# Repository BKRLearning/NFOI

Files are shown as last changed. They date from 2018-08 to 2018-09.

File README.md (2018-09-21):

****
# Kitchen Mania
****
Kitchen Mania uses screen-based game control as a starting point for understanding and exploring new methods of interacting with physical computer interfaces. It uses familiar household appliances and tools to produce novel forms of human-computer interaction that are intuitive and accessible.

One the primary goals of Kitchen Mania is to achieve functional human interface devices that simultaneously perform real physical tasks. While playful, we believe these controllers show the viability of highly accurate / low latency passive sensing of existing electronic appliances. This work has applications in a range of smart home and IoT use cases.

Setup
=========
Lorem ipsum dolor sit amet, consectetur adipiscing elit, sed do eiusmod tempor incididunt ut labore et dolore magna aliqua. Ut enim ad minim veniam, quis nostrud exercitation ullamco laboris nisi ut aliquip ex ea commodo consequat. Duis aute irure dolor in reprehenderit in voluptate velit esse cillum dolore eu fugiat nulla pariatur. Excepteur sint occaecat cupidatat non proident, sunt in culpa qui officia deserunt mollit anim id est laborum.

PulpPad
=========
The PulpPad is a controller comprised of four electric juicers with interchangeable button mapping. For this demo, we have setup two PulpPads mapped in a D-pad configuration to StepMania, a Dance Dance Revolution simulator. Hand-dance battle your friends and drink some freshly squeezed juice after you play!

conROLLER
=========
The conROLLER is a rolling pin controller designed to work with single-axis games. Roll the pin to move your player on screen // use the thumb button to fire and activate the two attached relays. Fire up your pizza oven and make some own pizza after destroying enemy ships!

Project resources
=================
- [Website](http://www.brooklynresearch.org)
- [Source code](#)
- [Scematics](https://github.com/BKRLearning/NFOI/tree/master/Schematics)

License
=======
Copyright 2018 Brooklyn Research and contributors.
Licensed under MIT, Version 2.0. See the file LICENSE for the full license text.

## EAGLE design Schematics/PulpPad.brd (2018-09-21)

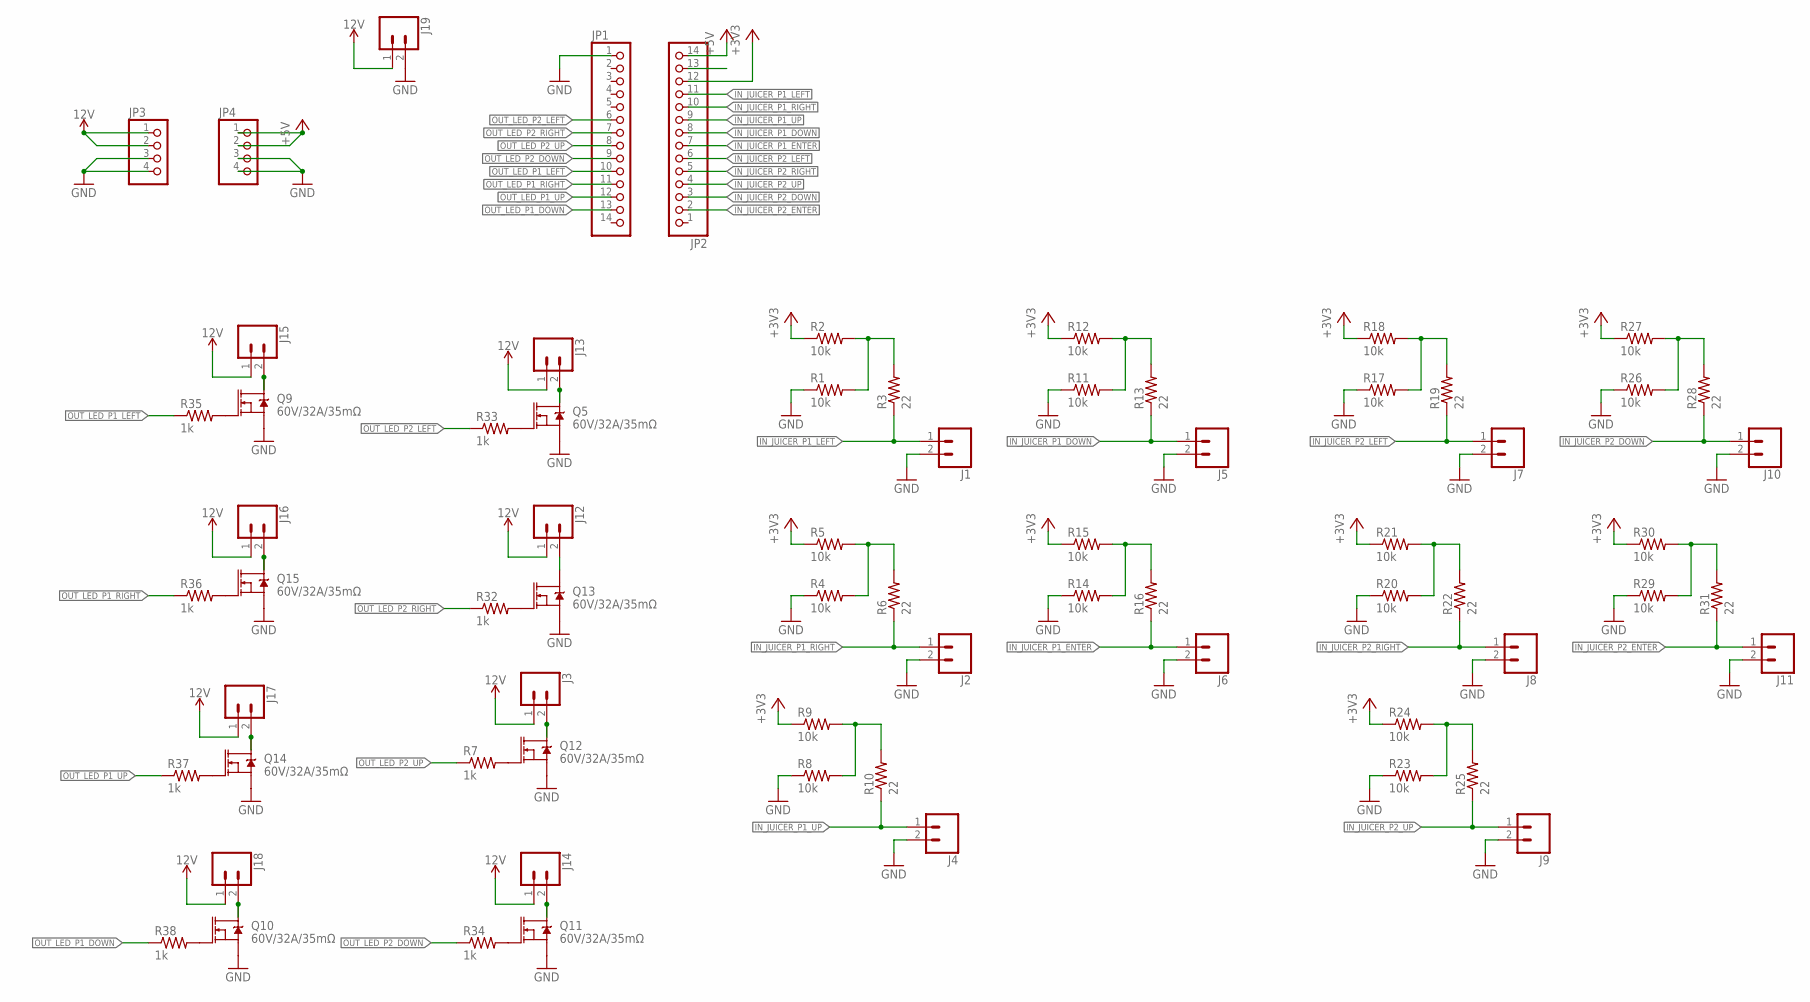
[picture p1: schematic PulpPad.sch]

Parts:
J1, J2, J3, J4, J5, J6, J7, J8, J9, J10, J11, J12, J13, J14, J15, J16, J17, J18, J19: CONN_023.5MM; SCREWTERMINAL-3.5MM-2
JP1, JP2: PINHD-1X14; 1X14
JP3, JP4: PINHD-1X4; 1X04
Q5, Q9, Q10, Q11, Q12, Q13, Q14, Q15: 60V/32A/35mΩ; TO220V
R1, R2, R4, R5, R8, R9, R11, R12, R14, R15, R17, R18, R20, R21, R23, R24, R26, R27, R29, R30: 10k; 0204/7
R3, R6, R10, R13, R16, R19, R22, R25, R28, R31: 22; 0204/7
R7, R32, R33, R34, R35, R36, R37, R38: 1k; 0204/7

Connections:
12V: J3.1, J12.1, J13.1, J14.1, J15.1, J16.1, J17.1, J18.1, J19.1, JP3.1, JP3.2
+3V3: JP2.12, R2.1, R5.1, R9.1, R12.1, R15.1, R18.1, R21.1, R24.1, R27.1, R30.1
+5V: JP2.14, JP4.1, JP4.2
GND: J1.2, J2.2, J4.2, J5.2, J6.2, J7.2, J8.2, J9.2, J10.2, J11.2, J19.2, JP1.1, JP3.3, JP3.4, JP4.3, JP4.4, Q5.3 (S), Q9.3 (S), Q10.3 (S), Q11.3 (S), Q12.3 (S), Q13.3 (S), Q14.3 (S), Q15.3 (S), R1.1, R4.1, R8.1, R11.1, R14.1, R17.1, R20.1, R23.1, R26.1, R29.1
IN_JUICER_P1_DOWN: J5.1, JP2.8, R13.1
IN_JUICER_P1_ENTER: J6.1, JP2.7, R16.1
IN_JUICER_P1_LEFT: J1.1, JP2.11, R3.1
IN_JUICER_P1_RIGHT: J2.1, JP2.10, R6.1
IN_JUICER_P1_UP: J4.1, JP2.9, R10.1
IN_JUICER_P2_DOWN: J10.1, JP2.3, R28.1
IN_JUICER_P2_ENTER: J11.1, JP2.2, R31.1
IN_JUICER_P2_LEFT: J7.1, JP2.6, R19.1
IN_JUICER_P2_RIGHT: J8.1, JP2.5, R22.1
IN_JUICER_P2_UP: J9.1, JP2.4, R25.1
unnamed: R1.2, R2.2, R3.2
unnamed: Q15.1 (G), R36.2
unnamed: J3.2, Q12.2 (D)
unnamed: R8.2, R9.2, R10.2
unnamed: R4.2, R5.2, R6.2
unnamed: R11.2, R12.2, R13.2
unnamed: R14.2, R15.2, R16.2
unnamed: R17.2, R18.2, R19.2
unnamed: R20.2, R21.2, R22.2
unnamed: R23.2, R24.2, R25.2
unnamed: R26.2, R27.2, R28.2
unnamed: R29.2, R30.2, R31.2
unnamed: Q14.1 (G), R37.2
unnamed: J12.2, Q13.2 (D)
unnamed: Q10.1 (G), R38.2
unnamed: J13.2, Q5.2 (D)
unnamed: Q5.1 (G), R33.2
unnamed: J14.2, Q11.2 (D)
unnamed: Q9.1 (G), R35.2
unnamed: J15.2, Q9.2 (D)
unnamed: Q13.1 (G), R32.2
unnamed: J16.2, Q15.2 (D)
unnamed: Q12.1 (G), R7.2
unnamed: J17.2, Q14.2 (D)
unnamed: Q11.1 (G), R34.2
unnamed: J18.2, Q10.2 (D)
OUT_LED_P1_DOWN: JP1.13, R38.1
OUT_LED_P1_LEFT: JP1.10, R35.1
OUT_LED_P1_RIGHT: JP1.11, R36.1
OUT_LED_P1_UP: JP1.12, R37.1
OUT_LED_P2_DOWN: JP1.9, R34.1
OUT_LED_P2_LEFT: JP1.6, R33.1
OUT_LED_P2_RIGHT: JP1.7, R32.1
OUT_LED_P2_UP: JP1.8, R7.1

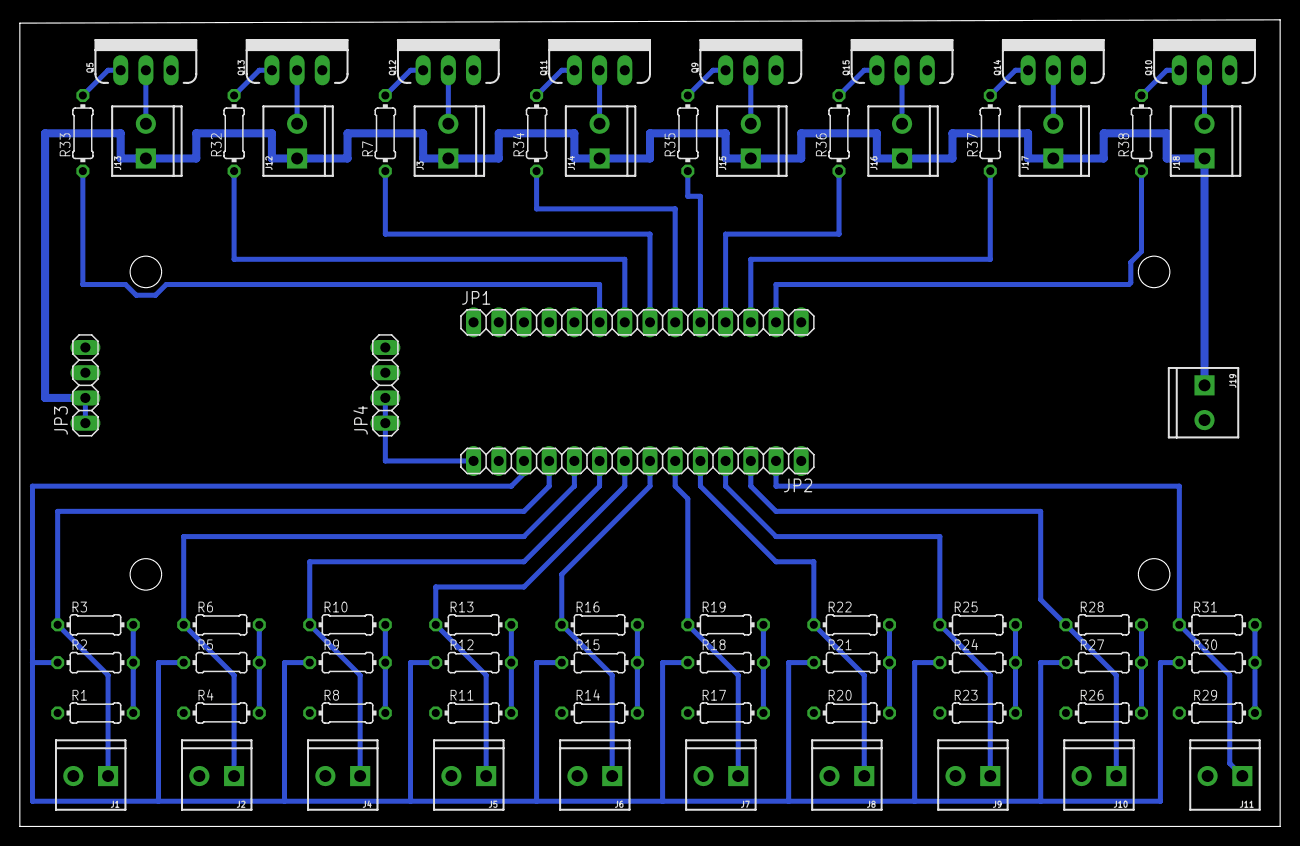
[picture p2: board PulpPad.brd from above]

Board: 2 copper layers, 127.0 x 81.3 mm, 69 parts (0 on the bottom side), 48 nets.

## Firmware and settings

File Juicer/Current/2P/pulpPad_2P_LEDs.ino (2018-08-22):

/****************************************

  Pulp Pad Controller

  Description text to go here...
  ... 
  ...

  Created August 14, 2018
  By Nick Wallace <ntwallace@gmail.com> for Brooklyn Research: New Forms of Interaction
  http://www.github.com/BKRLearning/NFOI/blob/master/Juicer/current/

  This code is free software under the MIT liscense, all text above must be included in any redistribution.

****************************************/
 

//
//  Define input and output pins 
//
//  *** default is 2p, 4 juicers + 1 enter button per player -- add define statments for additional players, modify totalPlayers variable ***
//


// input pins for juicers
#define JUICER_P1_LEFT 23
#define JUICER_P1_RIGHT 22
#define JUICER_P1_UP 21
#define JUICER_P1_DOWN 20
#define JUICER_P1_ENTER 19

#define JUICER_P2_LEFT 18
#define JUICER_P2_RIGHT 17
#define JUICER_P2_UP 16
#define JUICER_P2_DOWN 15
#define JUICER_P2_ENTER 14

// output pins for LEDs
#define LED_P1_LEFT 4
#define LED_P1_RIGHT 5
#define LED_P1_UP 6
#define LED_P1_DOWN 7
#define LED_P1_ENTER 0

#define LED_P2_LEFT 8
#define LED_P2_RIGHT 9
#define LED_P2_UP 10
#define LED_P2_DOWN 11
#define LED_P2_ENTER 0

// key press outputs
#define p1Left KEY_LEFT
#define p1Right KEY_RIGHT
#define p1Up KEY_UP
#define p1Down KEY_DOWN
#define p1Enter KEY_SPACE

#define p2Left KEY_A
#define p2Right KEY_D
#define p2Up KEY_W
#define p2Down KEY_S
#define p2Enter KEY_ENTER



//
// Setup Game Variables
//
// *** if totalPlayers is changed, modify define statments above for juicer input pins, LED output pins, key press mappings, and enter buttons ***
//

#define totalPlayers 2
#define totalJuicers ((totalPlayers * 4) + totalPlayers)    // 4 juicers + 1 start button per player

uint16_t juicerInputs[totalJuicers] = {JUICER_P1_LEFT, JUICER_P1_RIGHT, JUICER_P1_UP, JUICER_P1_DOWN, JUICER_P1_ENTER, JUICER_P2_LEFT, JUICER_P2_RIGHT, JUICER_P2_UP, JUICER_P2_DOWN, JUICER_P2_ENTER};
uint16_t juicerOutputKeys[totalJuicers] = {p1Left, p1Right, p1Up, p1Down, p1Enter, p2Left, p2Right, p2Up, p2Down, p2Enter};

uint16_t ledOutputs[totalJuicers] = {LED_P1_LEFT, LED_P1_RIGHT, LED_P1_UP, LED_P1_DOWN, LED_P1_ENTER, LED_P2_LEFT, LED_P2_RIGHT, LED_P2_UP, LED_P2_DOWN, LED_P2_ENTER};

/*uint16_t enterButtons[totalPlayers] = {JUICER_P1_ENTER, JUICER_P2_ENTER};
uint16_t enterOutputKeys[totalPlayers] = {p1Enter, p2Enter};*/



//
// Setup Arrays for Gameplay
//

// juicer pressed/released bools, to be in order L, R, U, D, Enter for p1 & p2
byte juicersPressed[totalJuicers];
byte juicersReleased[totalJuicers];

// juicer analog readings, to be in order L, R, U, D, Enter for p1 & p2
uint16_t baselineVals[totalJuicers];
uint16_t currentVals[totalJuicers];
uint16_t previousVals[totalJuicers];

// pressed juicer running avg values
const byte arraySize = 6;
long pushedVals[totalJuicers][arraySize];    // 2D array contains array for each juicer with the last "arraySize" readings of each juicer to use for averaging
byte readIndexes[totalJuicers];
long totals[totalJuicers];
float averages[totalJuicers];

// setup millis delay
long startMillis;
long currentMillis;
const long period = 10;



void setup() {
  Serial.begin(9600);

  startMillis = millis();

  initJuicers();  // initialize juicer array vals
}

void loop() {

  currentMillis = millis();
  if (currentMillis - startMillis >= period) {  // run this code every "period" (in ms)

    //getEnterButtons(); // check if enters buttons have been pressed
    getJuicerVals(); // get current vals for each juicer

    for (int i = 0; i < totalJuicers; i++) {
      if (juicersPressed[i]) {  // if a particular juicer was pressed, then...
        totals[i] = totals[i] - pushedVals[i][readIndexes[i]];  // subtract the last value from the running total
        pushedVals[i][readIndexes[i]] = currentVals[i]; // get the new pressed value from the current value array
        totals[i] = totals[i] + pushedVals[i][readIndexes[i]]; // add that value to the running total
        readIndexes[i]++; // update the index

        if (readIndexes[i] >= arraySize) {  // reset the index number once it gets to the max array size
          readIndexes[i] = 0;
        }

        averages[i] = totals[i] / arraySize;
        delay(1);

        if (abs(averages[i] - baselineVals[i]) <= 3)  {  // check if the difference between the running avg and the baseline val for any juicer is within 2
          juicersReleased[i] = true;
          juicersPressed[i] = false;
        }
      }
      delay(1);
    }

    startMillis = currentMillis;
  }


  getJuicersPressed();    // check if player has pressed juicer
  getJuicersReleased();   // check if player has released juicer

  delay(1);
}

void initJuicers() {  // get juicer baseline readings & initialize arrays and LEDs
  for (int i = 0; i < totalJuicers; i++) {
    baselineVals[i] = analogRead(juicerInputs[i]);

    pinMode(ledOutputs[i], OUTPUT);

    // arrays in order L, R, U, D, E for p1 & p2
    juicersPressed[i] = false;
    juicersReleased[i] = false;
    currentVals[i] = 0;
    previousVals[i] = 0;
    readIndexes[i] = 0;
    totals[i] = 0;
    averages[i] = 0;

    // init running avg 2D array
    for (int j = 0; j < arraySize; j++) {
      pushedVals[i][j] = 0;
    }
  }
}


void getJuicerVals() {  // get current values for each juicer
  for (int i = 0; i < totalJuicers; i++) {
    previousVals[i] = currentVals[i];
    currentVals[i] = analogRead(juicerInputs[i]);
  }

  delay(1);
}



void getJuicersPressed() {  // check if player has pressed juicer
  for (int i = 0; i < totalJuicers; i++) {
    if (!juicersReleased[i] && abs(previousVals[i] - currentVals[i]) >= 15) { // actively pressing juicer if dif between previous and current val within 15
      juicersPressed[i] = true;

      Keyboard.press(juicerOutputKeys[i]); // press corresponding output key, in order p1 L, R, U, D, E -> p2 L, R, U, D, E
      digitalWrite(ledOutputs[i], HIGH);

      Serial.print("Juicer: ");
      Serial.print(juicerInputs[i]);
      Serial.print(" was pressed");
      Serial.println();
    }
    delay(1);
  }
}

void getJuicersReleased() {  // check if juicer has been released after being pressed
  for (int i = 0; i < totalJuicers; i++) {
    if (!juicersPressed[i] && juicersReleased[i]) {
      Keyboard.release(juicerOutputKeys[i]);
      digitalWrite(ledOutputs[i], LOW);

      Serial.print("Juicer: ");
      Serial.print(juicerInputs[i]);
      Serial.print(" was released");
      Serial.println();

      // reset averaging array setup for that juicer
      for (int j = 0; j < arraySize; j++) {
        pushedVals[i][j] = 0;
      }
      totals[i] = 0;

      // reset state vals for that juicer
      juicersPressed[i] = false;
      juicersReleased[i] = false;

    }

    delay(1);
  }
}

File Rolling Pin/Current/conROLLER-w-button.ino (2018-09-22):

#include <Encoder.h>
#include <Bounce.h>

#define RUMBLE_LEFT 21
#define RUMBLE_RIGHT 20
#define START_PIN 16
#define BUTTON_PIN 15
#define FOOD_PROCESSOR_PIN 14
#define BLENDER_PIN 13

Bounce pushbutton = Bounce(BUTTON_PIN, 5);  // 5ms debounce
Bounce startButton = Bounce(START_PIN, 5);  // 5ms debounce
byte buttonState, previousState;

Encoder knob(6, 7);
long currentPos, secondPos;

const long releaseDelay = 40;  // delay in ms before button releases

long startMillis;
long currentMillis;
long motorMillis;
const long period = 10; // delay in ms between analog reads

void setup() {
  Serial.begin(9600);
  startMillis = millis();  // start countdown clock for non blocking delay

  pinMode(BUTTON_PIN, INPUT_PULLUP);
  //pinMode(START_PIN, INPUT_PULLUP);
  pinMode(FOOD_PROCESSOR_PIN, OUTPUT);
  pinMode(BLENDER_PIN, OUTPUT);
  pinMode(RUMBLE_LEFT, OUTPUT);
  pinMode(RUMBLE_RIGHT, OUTPUT);

  // get knob state
  currentPos = knob.read();
  secondPos = currentPos - 1;

  // get button state
  buttonState = digitalRead(BUTTON_PIN);
  previousState = HIGH;
}

void loop() {
  pushbutton.update();  // get button status
  startButton.update();

  // read encoder values at defined period (non blocking)
  currentMillis = millis();
  if (currentMillis - startMillis >= period)
  {
    currentPos = knob.read();
    startMillis = currentMillis;
  }

  updateMotorStatus();
  getStartButtonPress();
  getButtonPress();  // check if button was pressed, activate appliances
  getPinMovement(); // check if pin has been rolled, move player

}

void updateMotorStatus() {
  if (millis() - motorMillis >= (releaseDelay * 10))
  {
    analogWrite(RUMBLE_LEFT, 0);
    analogWrite(RUMBLE_RIGHT, 0);
  } else {
    analogWrite(RUMBLE_LEFT, 255);
    analogWrite(RUMBLE_RIGHT, 255);
  }
}

void getStartButtonPress() {
  if (startButton.fallingEdge()) {
    Keyboard.press(KEY_ENTER);
    delay(releaseDelay);  // has to be long enough that keypress is registered by computer
    Keyboard.release(KEY_ENTER);
  }
}

void getButtonPress() {
  if (pushbutton.fallingEdge()) {    // button was pressed

    Serial.println("Button pressed");
    
    // turn appliances on
    digitalWrite(FOOD_PROCESSOR_PIN, HIGH);
    digitalWrite(BLENDER_PIN, HIGH);
    Keyboard.press(KEY_A);
    
    motorMillis = millis(); // reset vibration timing
    delay(releaseDelay);  // has to be long enough that keypress is registered by computer & mechanical devices are powered on long enough for effect (min 20ms)

    // turn appliances off
    digitalWrite(FOOD_PROCESSOR_PIN, LOW);
    digitalWrite(BLENDER_PIN, LOW);
    Keyboard.release(KEY_A);
  }
}


void getPinMovement() {
  if (currentPos != secondPos) {      // knob has been turned
    if (currentPos > secondPos) {     // moving forward
      Serial.println("Moving forward...");
      Keyboard.press(KEY_RIGHT);
    } else {                          // moving backwards
      Serial.println("Moving backward...");
      Keyboard.press(KEY_LEFT);
    }
    secondPos = currentPos;

  } else {
    delay(releaseDelay);  // has to be long enough that keypress is registered by computer
    Keyboard.release(KEY_LEFT);
    Keyboard.release(KEY_RIGHT);
  }
}

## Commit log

2018-07-23 Add folder structure, push rolling pin code
2018-07-23 Updated current multi averaging code
2018-08-05 add juicer with led code
2018-08-14 Added sketch with 2P & LEDs
    [conRoller.fzz, pulpPads.fzz]
2018-08-14 Updated enter button code, added additional comments
2018-08-14 Fixed button key presses, added comments
    [pulpPad_2P_LEDs.ino]
2018-08-22 Fixed enter buttons, updated delay
    [pulpPad_2P_LEDs.ino]
2018-09-21 Added PulpPad schematics, reorg code
    [PulpPad.brd, PulpPad.sch, pulpPads.fzz]

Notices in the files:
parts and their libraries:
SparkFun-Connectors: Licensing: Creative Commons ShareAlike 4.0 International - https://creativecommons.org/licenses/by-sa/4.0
